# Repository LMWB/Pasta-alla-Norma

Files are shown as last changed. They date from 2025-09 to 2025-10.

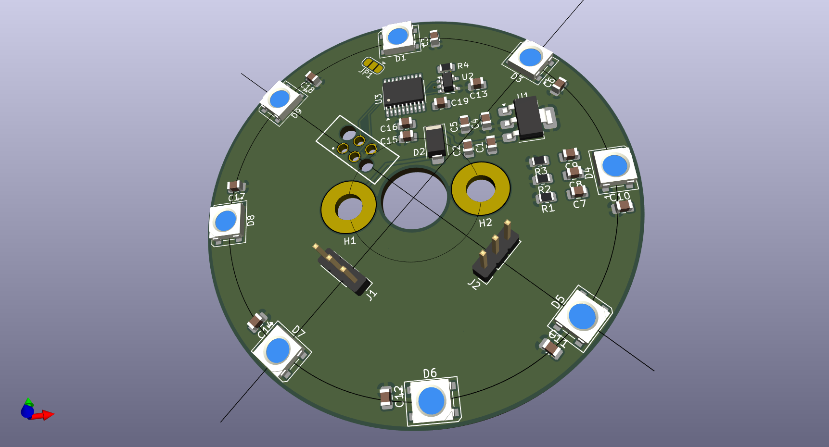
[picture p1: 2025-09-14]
Hardware/lmwb_RGB_Ball.png

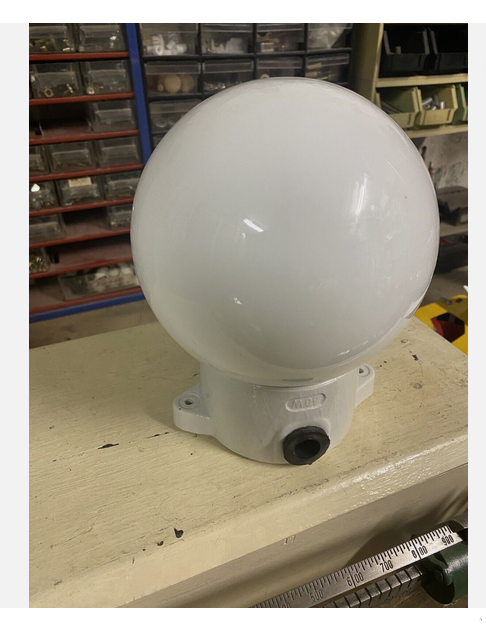
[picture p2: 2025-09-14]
Hardware/DDR-Keller-Lampe.png

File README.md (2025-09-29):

# Pasta_alla_Norma
Circular shaped RGB-LED PCB with integrated Microcontroller and EEPROM

# cubeIDE Setting for evaluate used flash size
```arm-none-eabi-nm --size-sort --print-size "RGB_Ring_LimbusZero.elf" > "RGB_Ring_LimbusZero.sizes"```  

- T / t → Flash (code)  
- R / r → Flash (read-only const)  
- D / d → RAM (with init in Flash)  
- B / b → RAM only (zero-init)  
- W / w → Weak (depends where resolved, often Flash functions)  

# Fassung
E27 bedeutet Edison Fassung 27 mm (siehe Zeichnung).  
Ein zylindrischer Stempel der in die Fassung passt ohne Gewinde, sollte 30mm Lange haben und 24mm Durchmesser.

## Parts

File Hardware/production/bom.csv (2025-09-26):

Designator | Footprint | Quantity | Value | LCSC Part #
C1, C16, C5 | 0805 | 3 | 22u | C45783
C10, C11, C12, C13, C14, C15, C17, C18, C19, C3, C6, C7, C8, C9 | 0805 | 14 | 100n | C49678
C2, C4 | 0805 | 2 | 1u | C28323
D2 | D_SMA | 1 | US1D | C95872
R1, R2, R3 | 0805 | 3 | 10k | C17414
R4 | 0805 | 1 | 0 | C17477
U1 | SOT-223-3_TabPin2 | 1 | AMS1117-3.3 | C6186
U2 | SOT-23-5 | 1 | 24C02S | C18723540
U3 | TSSOP-20_4.4x6.5mm_P0.65mm | 1 | STM32C011F6P6 | C5456198

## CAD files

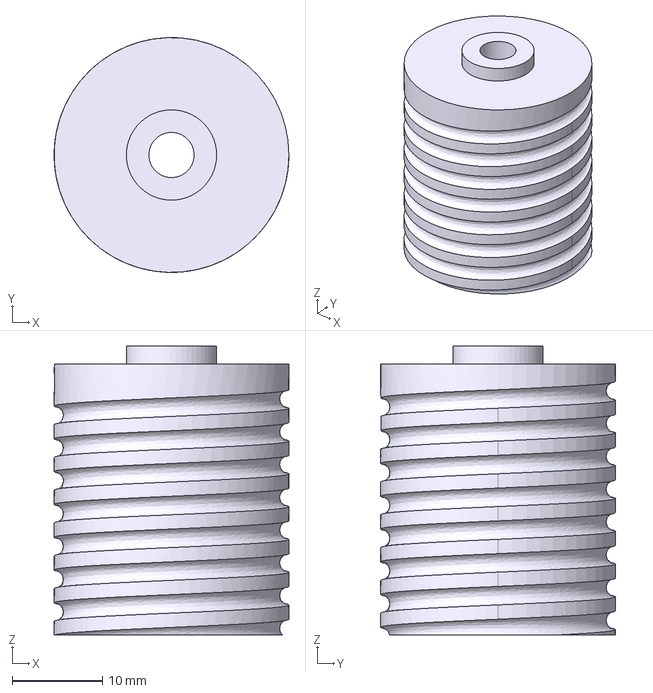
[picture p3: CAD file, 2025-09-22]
CAD/RGB-Ball-Fassung-Gewinde.step
26.0 x 26.0 x 32.0 mm

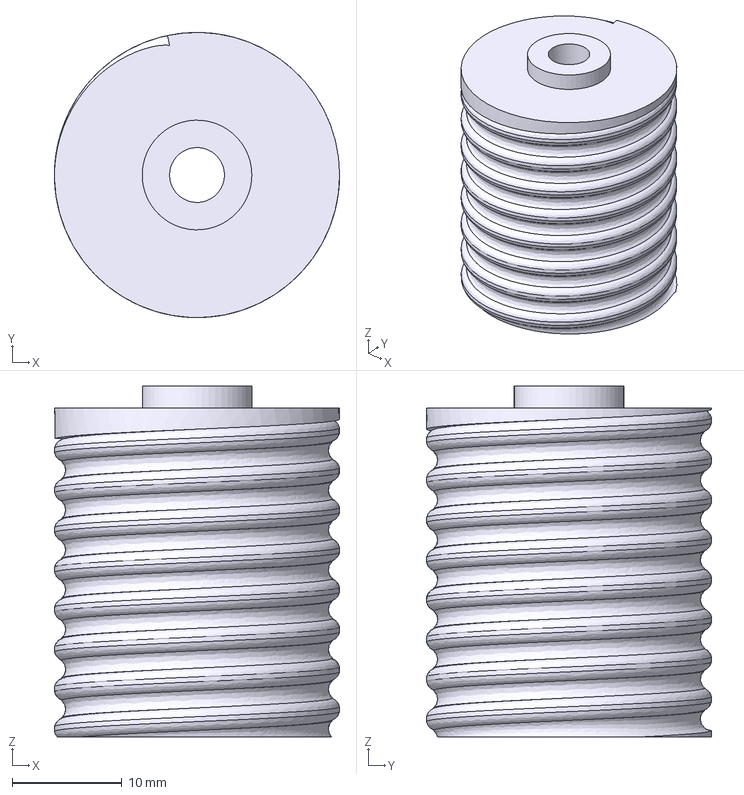
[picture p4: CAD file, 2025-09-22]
CAD/RGB-Ball-Fassung-Gewinde-Rund.step
26.0 x 26.0 x 32.0 mm

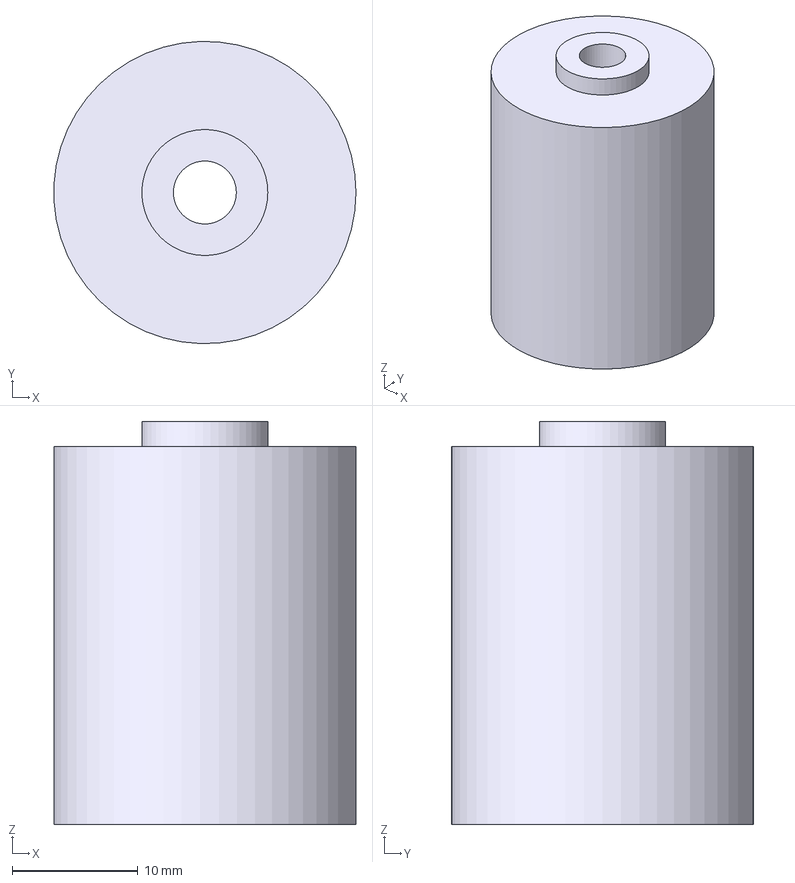
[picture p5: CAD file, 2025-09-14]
CAD/RGB-Ball-Fassung.step
24.0 x 24.0 x 32.0 mm

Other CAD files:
CAD/RGB-Ball-Fassung-Gewinde-Rund.FCStd
CAD/RGB-Ball-Fassung-Gewinde.FCStd
CAD/RGB-Ball-Fassung.FCStd

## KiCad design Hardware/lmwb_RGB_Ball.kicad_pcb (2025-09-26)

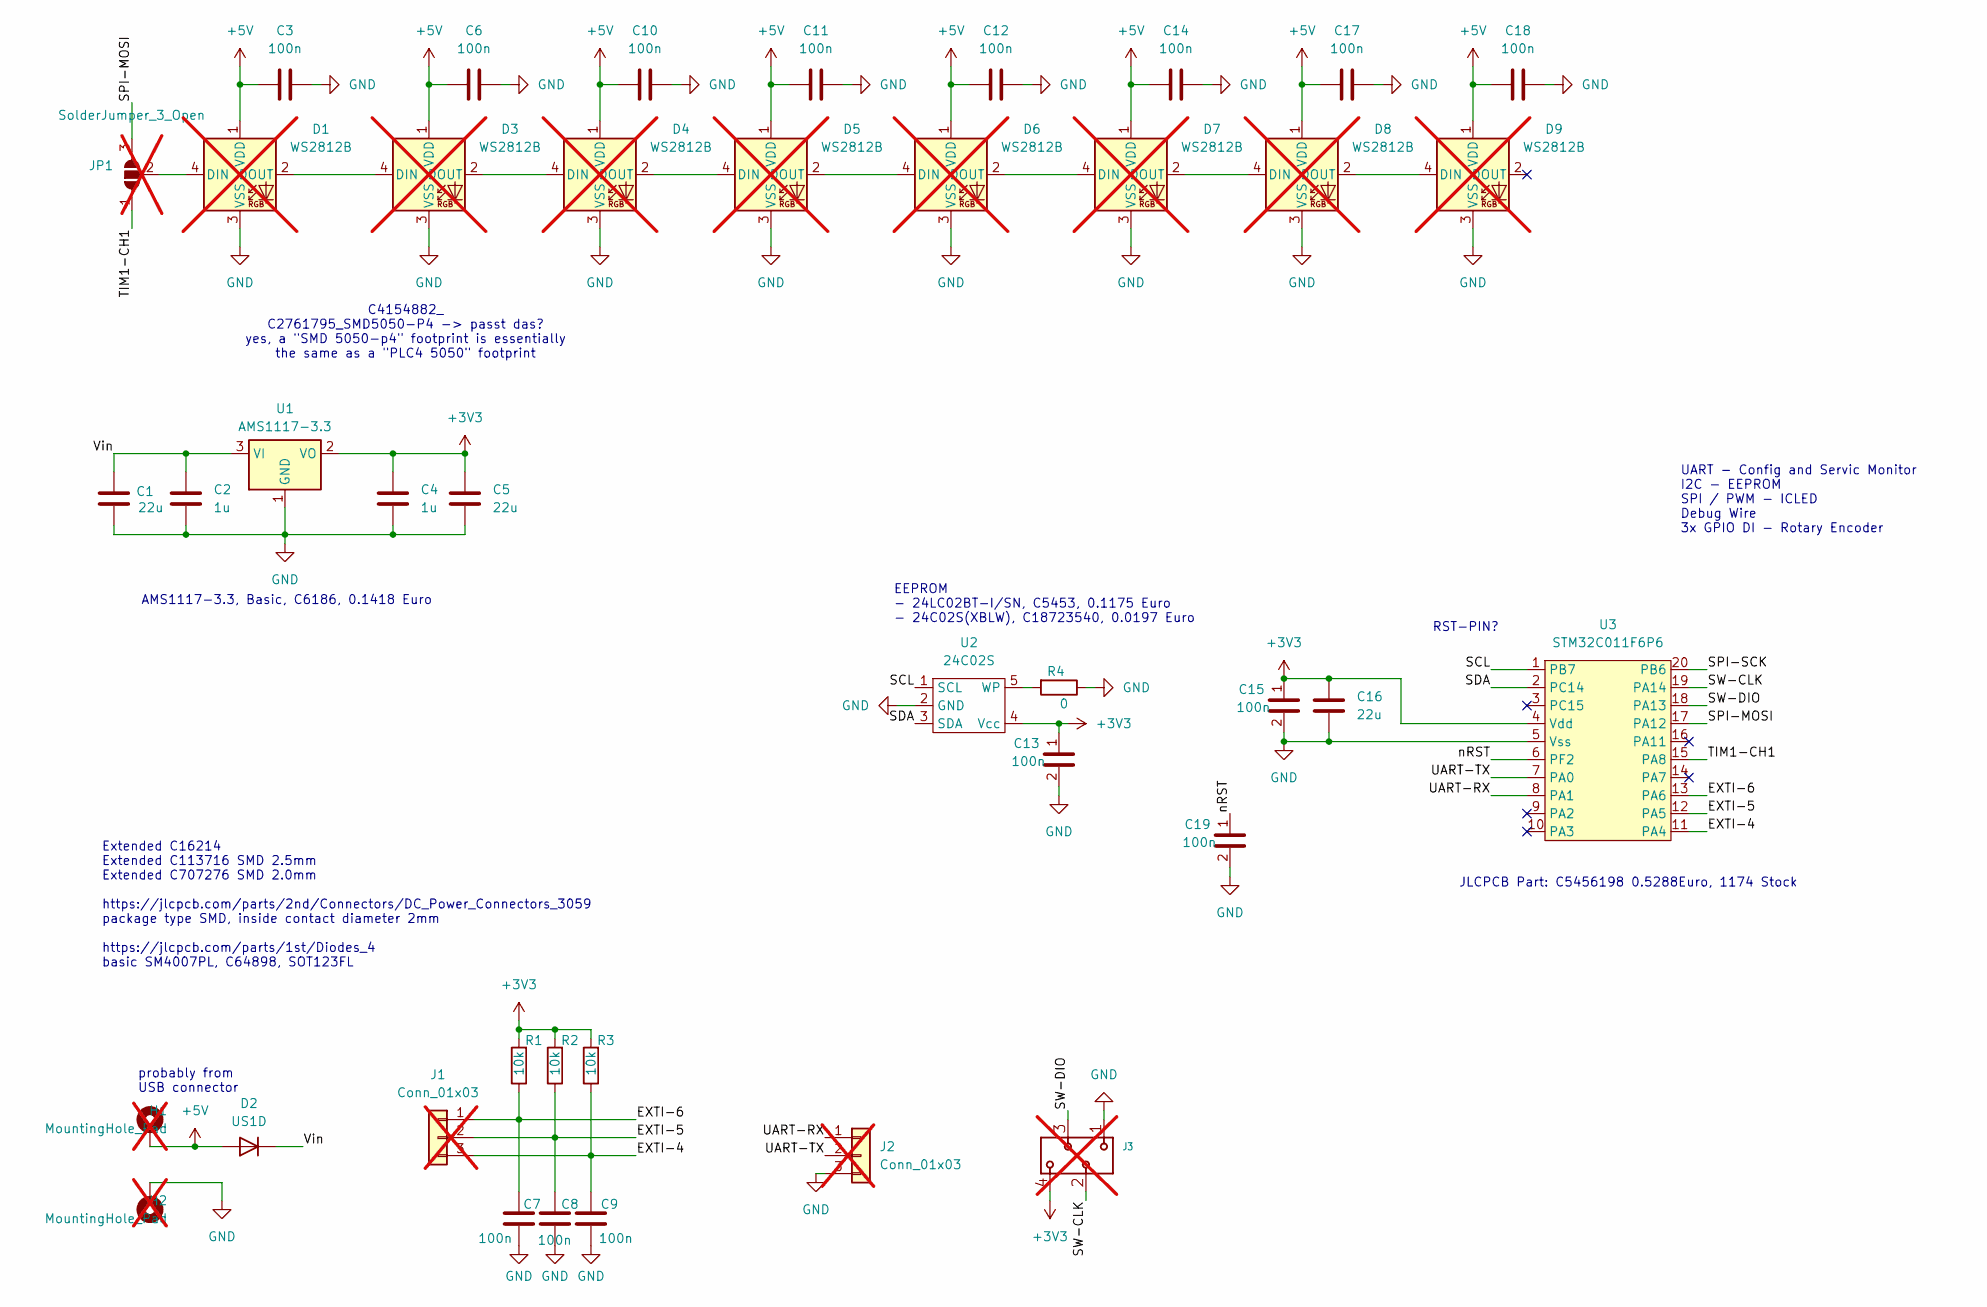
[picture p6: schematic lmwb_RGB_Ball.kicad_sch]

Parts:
C1, C5, C16: 22u; C_0805_2012Metric; LCSC PN C45783
C2, C4: 1u; C_0805_2012Metric; LCSC PN C28323
C3, C6, C7, C8, C9, C10, C11, C12, C13, C14, C15, C17, C18, C19: 100n; C_0805_2012Metric; LCSC PN C49678
D1, D3, D4, D5, D6, D7, D8, D9: WS2812B; LED_WS2812B_PLCC4_5.0x5.0mm_P3.2mm; LCSC PN C2761795; not fitted
D2: US1D; D_SMA; LCSC PN C95872
H1, H2: MountingHole_Pad; MountingHole_4.3mm_M4_Pad; not fitted
J1, J2: Conn_01x03; PinHeader_1x03_P2.54mm_Vertical; not fitted
J3: 490107670412_DEBUGGING; not fitted
JP1: SolderJumper_3_Open; SolderJumper-3_P1.3mm_Open_RoundedPad1.0x1.5mm; not fitted
R1, R2, R3: 10k; R_0805_2012Metric; LCSC PN C17414
R4: 0; R_0805_2012Metric; LCSC PN C17477
U1: AMS1117-3.3; SOT-223-3_TabPin2; LCSC PN C6186
U2: 24C02S; SOT-23-5; LCSC PN C18723540
U3: STM32C011F6P6; TSSOP-20_4.4x6.5mm_P0.65mm; LCSC PN C5456198

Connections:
+3V3: C4.1, C5.1, C13.1, C15.1, C16.1, J3.4, R1.2, R2.2, R3.2, U1.2 (VO), U2.4 (Vcc), U3.4 (Vdd)
+5V: C3.1, C6.1, C10.1, C11.1, C12.1, C14.1, C17.1, C18.1, D1.1 (VDD), D2.2 (A), D3.1 (VDD), D4.1 (VDD), D5.1 (VDD), D6.1 (VDD), D7.1 (VDD), D8.1 (VDD), D9.1 (VDD), H1.1
/EXTI-4: C9.1, J1.3, R3.1, U3.11 (PA4)
/EXTI-5: C8.1, J1.2, R2.1, U3.12 (PA5)
/EXTI-6: C7.1, J1.1, R1.1, U3.13 (PA6)
/SCL: U2.1 (SCL), U3.1 (PB7)
/SDA: U2.3 (SDA), U3.2 (PC14)
/SPI-MOSI: JP1.3 (B), U3.17 (PA12)
/SPI-SCK: U3.20 (PB6)
/SW-CLK: J3.2, U3.19 (PA14)
/SW-DIO: J3.3, U3.18 (PA13)
/TIM1-CH1: JP1.1 (A), U3.15 (PA8)
/UART-RX: J2.1, U3.8 (PA1)
/UART-TX: J2.2, U3.7 (PA0)
/Vin: C1.1, C2.1, D2.1 (K), U1.3 (VI)
/nRST: C19.1, U3.6 (PF2)
GND: C1.2, C2.2, C3.2, C4.2, C5.2, C6.2, C7.2, C8.2, C9.2, C10.2, C11.2, C12.2, C13.2, C14.2, C15.2, C16.2, C17.2, C18.2, C19.2, D1.3 (VSS), D3.3 (VSS), D4.3 (VSS), D5.3 (VSS), D6.3 (VSS), D7.3 (VSS), D8.3 (VSS), D9.3 (VSS), H2.1, J2.3, J3.1, R4.1, U1.1 (GND), U2.2 (GND), U3.5 (Vss)
unnamed: D1.4 (DIN), JP1.2 (C)
unnamed: D1.2 (DOUT), D3.4 (DIN)
unnamed: D3.2 (DOUT), D4.4 (DIN)
unnamed: D4.2 (DOUT), D5.4 (DIN)
unnamed: D5.2 (DOUT), D6.4 (DIN)
unnamed: D6.2 (DOUT), D7.4 (DIN)
unnamed: D7.2 (DOUT), D8.4 (DIN)
unnamed: D8.2 (DOUT), D9.4 (DIN)
unnamed: R4.2, U2.5 (WP)

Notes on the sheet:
UART - Config and Servic Monitor I2C - EEPROM SPI / PWM - ICLED Debug Wire 3x GPIO DI - Rotary Encoder
probably from USB connector
EEPROM - 24LC02BT-I/SN, C5453, 0.1175 Euro - 24C02S(XBLW), C18723540, 0.0197 Euro
RST-PIN?
AMS1117-3.3, Basic, C6186, 0.1418 Euro
JLCPCB Part: C5456198 0.5288Euro, 1174 Stock
Extended C16214 Extended C113716 SMD 2.5mm Extended C707276 SMD 2.0mm https://jlcpcb.com/parts/2nd/Connectors/DC_Power_Connectors_3059 package type SMD, inside contact diameter 2mm https://jlcpcb.com/parts/1st/Diodes_4 basic SM4007PL, C64898, SOT123FL
C4154882_ C2761795_SMD5050-P4 -> passt das? yes, a "SMD 5050-p4" footprint is essentially the same as a "PLC4 5050" footprint

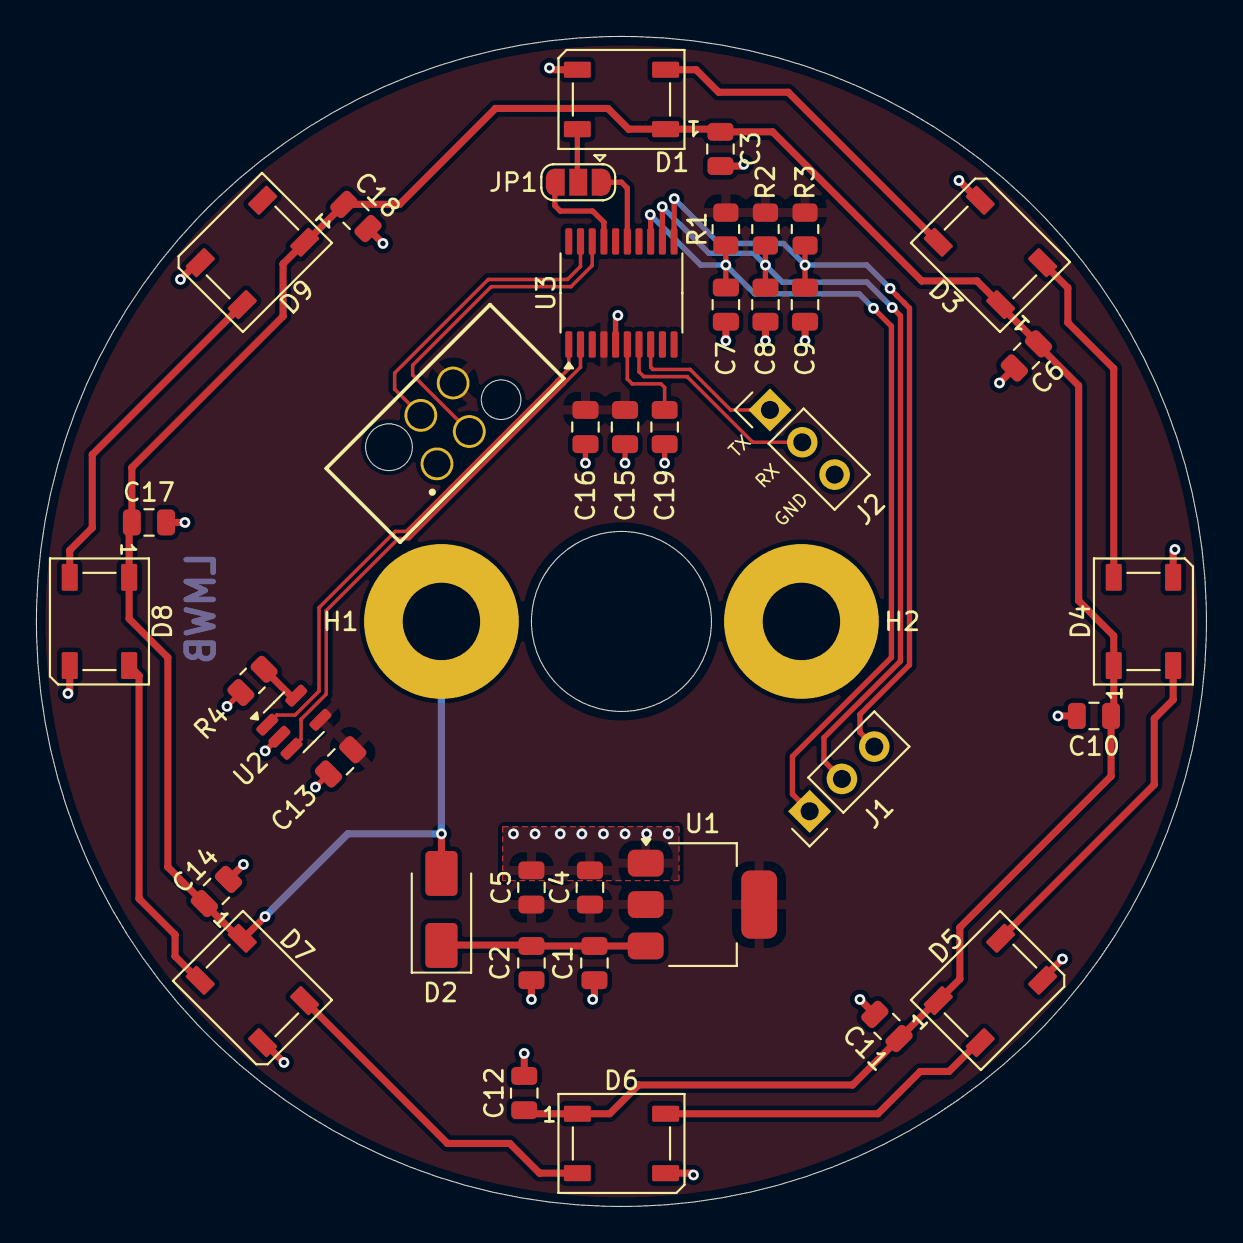
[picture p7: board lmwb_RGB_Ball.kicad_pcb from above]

Board: 2 copper layers, 65.0 x 65.0 mm, 41 parts (0 on the bottom side), 25 nets.

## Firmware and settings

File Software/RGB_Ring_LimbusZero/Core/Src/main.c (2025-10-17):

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
/* Includes ------------------------------------------------------------------*/
#include "main.h"
#include "dma.h"
#include "i2c.h"
#include "spi.h"
#include "tim.h"
#include "usart.h"
#include "gpio.h"

/* USER CODE BEGIN Includes */
#include "RGB_Ball/rgb_ball.h"
/* USER CODE END Includes */


void SystemClock_Config(void);
/**
  * @brief  The application entry point.
  * @retval int
  */
int main(void)
{

  /* MCU Configuration--------------------------------------------------------*/

  /* Reset of all peripherals, Initializes the Flash interface and the Systick. */
  HAL_Init();

  /* Configure the system clock */
  SystemClock_Config();

  /* Initialize all configured peripherals */
  MX_GPIO_Init();
  MX_DMA_Init();
  MX_SPI1_Init();
  MX_USART1_UART_Init();
  MX_I2C1_Init();
  MX_TIM1_Init();
  /* USER CODE BEGIN 2 */

  rgb_ball_init();
  uint8_t mode = rgb_ball_read_jumpers();

  switch (mode) {
	case 1:
		rgb_ball_blink(1);
		sunstorm_cycle();

		break;
	case 2:
		rgb_ball_blink(2);
		rgb_ball_christmas_color_fade();
		break;
	case 3:
		rgb_ball_blink(3);
		rgb_ball_rainbow_fade();
		break;
	default:
		break;
}

  // never get here!

  /* USER CODE END 2 */

  /* Infinite loop */
  /* USER CODE BEGIN WHILE */
  while (1)
  {
    /* USER CODE END WHILE */

    /* USER CODE BEGIN 3 */

  }
  /* USER CODE END 3 */
}

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


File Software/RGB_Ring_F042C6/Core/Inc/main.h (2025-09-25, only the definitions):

#define DI18_Pin GPIO_PIN_13
#define DI18_GPIO_Port GPIOC
#define DI16_Pin GPIO_PIN_0
#define DI16_GPIO_Port GPIOA
#define DI14_Pin GPIO_PIN_1
#define DI14_GPIO_Port GPIOA
#define DI12_Pin GPIO_PIN_2
#define DI12_GPIO_Port GPIOA
#define DI10_Pin GPIO_PIN_3
#define DI10_GPIO_Port GPIOA
#define DI8_Pin GPIO_PIN_4
#define DI8_GPIO_Port GPIOA
#define DI6_Pin GPIO_PIN_5
#define DI6_GPIO_Port GPIOA
#define DI4_Pin GPIO_PIN_6
#define DI4_GPIO_Port GPIOA
#define DI2_Pin GPIO_PIN_7
#define DI2_GPIO_Port GPIOA
#define DI1_Pin GPIO_PIN_0
#define DI1_GPIO_Port GPIOB
#define DI3_Pin GPIO_PIN_1
#define DI3_GPIO_Port GPIOB
#define DI5_Pin GPIO_PIN_2
#define DI5_GPIO_Port GPIOB
#define DI7_Pin GPIO_PIN_10
#define DI7_GPIO_Port GPIOB
#define DI9_Pin GPIO_PIN_11
#define DI9_GPIO_Port GPIOB
#define LED1_Pin GPIO_PIN_12
#define LED1_GPIO_Port GPIOB
#define LED2_Pin GPIO_PIN_13
#define LED2_GPIO_Port GPIOB
#define LED_TX_Pin GPIO_PIN_14
#define LED_TX_GPIO_Port GPIOB
#define LED_RX_Pin GPIO_PIN_15
#define LED_RX_GPIO_Port GPIOB
#define LED_RX_EXTI_IRQn EXTI4_15_IRQn
#define LED3_Pin GPIO_PIN_9
#define LED3_GPIO_Port GPIOA
#define EEPROM_nCS_Pin GPIO_PIN_15
#define EEPROM_nCS_GPIO_Port GPIOA
#define DI11_Pin GPIO_PIN_6
#define DI11_GPIO_Port GPIOB
#define DI13_Pin GPIO_PIN_7
#define DI13_GPIO_Port GPIOB
#define DI15_Pin GPIO_PIN_8
#define DI15_GPIO_Port GPIOB
#define DI17_Pin GPIO_PIN_9
#define DI17_GPIO_Port GPIOB

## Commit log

2025-08-28 created project structure
    [lmwb_RGB_Ball.kicad_pcb, lmwb_RGB_Ball.kicad_sch]
2025-09-14 did some routing
    [lmwb_RGB_Ball.kicad_pcb, lmwb_RGB_Ball.kicad_sch]
2025-09-14 added freeCAD Model
    [RGB-Ball-Fassung.FCStd, RGB-Ball-Fassung.step, lmwb_RGB_Ball.kicad_pcb]
2025-09-22 added CAD files adn step files
    [RGB-Ball-Fassung-Gewinde-Rund.FCStd, RGB-Ball-Fassung-Gewinde-Rund.step, RGB-Ball-Fassung-Gewinde.FCStd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]
2025-09-25 added F04xx project, coded firmware, progress on layout
    [lmwb_RGB_Ball.kicad_pcb, lmwb_RGB_Ball.kicad_sch]
2025-09-26 progress on layout
    [lmwb_RGB_Ball.kicad_pcb, lmwb_RGB_Ball.kicad_sch]
2025-09-26 order pcb and assambly
    [bom.csv, designators.csv, lmwb_RGB_Ball.kicad_pcb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]
2025-10-11 LED toggle wrapper
2025-10-11 read / write pin wrapper
2025-10-17 software adjustments to fit target PCB
2025-10-17 synch SW changes from target PCB to LimbusZero Dev Platform

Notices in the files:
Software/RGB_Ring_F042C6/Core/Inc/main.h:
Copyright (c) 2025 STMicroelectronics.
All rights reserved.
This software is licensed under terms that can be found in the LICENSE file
